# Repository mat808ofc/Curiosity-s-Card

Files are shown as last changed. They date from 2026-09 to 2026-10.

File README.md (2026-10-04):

# Curiosity's Card

### About
This is a custom business card with a nfc chip "NT3H2111W0FHKH", antenna "NXP's official Class 4 antenna" and a low-current 0603 package red LED, Vishay's "TLMS1000-GS15", which at 2mA (it's tested current for usage) only needs 1.75V (according to the Vf vs. If graphic in the datasheet). This is because the LED will work with the chip's energy harvesting feature, which will "harvest" energy from the nfc device (like a phone). The total voltage the chip can usually output with this technique is 2V, so the LED is inside the budget. I used the Ohm's Law to find the resistor value for the LED. 

R = (V_supply - V_LED) / I_desired

Vf - The forward voltage is the voltage it needs for a given current.
If - The forward current is the current actually flowing through the LED. Controls brightness. This is the value you target. Everything else in the calculation exists to make sure this number ends up where you want it.
They are related to each other. When more current flows through, Vf goes up as well.
V_supply: the total voltage available from the source (VOUT, ~2V in this case)
V_LED (Vf): the voltage the LED itself consumes at THE CHOSEN CURRENT!!

R = (2 − 1.75) / 0.002A = 125Ω, which is approx. 130Ω.

Aside from calculations, I also added personal branding, the Hack Club logo, some cool gradients, a qr code to my github repos and a section with most of the SMD package sizes (It's fun).

### INSPIRATION:
I haven't done projects for quite a long time because I was exhausted from it since the Flight controller (I was also working on my RC plane) so I decided to make a little weekend project, a custom business card, which is also I have honestly been wanting to make for quite a while now.

### CHALLENGES:
My biggest challenge was understanding the math and physics for the LED, it seemed super confusing at first but now I get it, and it makes a lot of sense. I also found it hard to understand the nfc chip and tag, but I ended up figuring it out.

### BOM:
| Part | MFR.Part # | Qty | Total Cost (USD) |  Link to part (lcsc) | Distributor |
|---|---|---|---|---|---|
| C1 (200nf 0603 capacitor) |  0603B204K160CT |  20 | $0.9140 | https://www.lcsc.com/pt/product-detail/C3833176.html?s_z=n_q_0603B204K160CT | JLCPCB |
| D1 (TLMS1000 0603 LED) |  TLMS1000-GS15 |  5 | $0.8605 | https://www.lcsc.com/pt/product-detail/C23070302.html?s_z=n_q_TLMS1000-GS15 | JLCPCB |
| R1 (130Ω 0402 resistor) |  RC0402FR-07130RL |  20 | $0.0800 | https://www.lcsc.com/pt/product-detail/C477610.html?s_z=n_q_RC0402FR-07130RL | JLCPCB |
| U1 (NXP NT3H2111W0FHKH) |  NT3H2111W0FHKH |  2 | $1.2324 | https://www.lcsc.com/pt/product-detail/C710403.html?s_z=n_q_NT3H2111W0FHKH | JLCPCB |
| Total: $3,0869 |

JLCPCB quote for assembly of 2 boards + shipping (Global Standard Direct Line: $8.48) + components with -$10 coupon: $26.76
{DEB36AE8-D00F-4259-A287-6ED29371B2AF}

(You can find the excel full BOM file in the project files)

# Grand Total: $26.76

### Extras:

This project does not need a case or anything 3D printed or designed, it is just a business card.
If you have any questions, DM me on slack: Mateus (mateus.flecha808)

## Schematic
{6E333D57-6D36-4BEA-881A-1B5B8A142C3A}

## PCB
{DF59C323-F329-4ACC-A75C-B1E4562BDE57}

## Render
{6B454F27-4811-417E-BAE5-E6EDF0D340DB}
The resistors on the SMD package sizing sections WILL NOT be assembled on the pcb! It will just be the footprints to display the different sizes.

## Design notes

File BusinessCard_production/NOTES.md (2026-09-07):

Coil to LA/LB, GND to ground, FD left open or wired to an MCU/LED if the field-detect feature is wanted, and EP (exposed pad) left open/floating per the datasheet.

No pours, no wires, no NOTHING near the coil and chip.

The chip can be near the coil.

LA/LB can be wired freely to the chip.

nfc is interesting

**The basic LED resistor formula:**

R = (V\_supply - V\_LED) / I\_desired

Vf - The forward voltage is the voltage it needs for a given current.

If - The forward current is the current actually flowing through the LED. Controls brightness. This is the value you target. Everything else in the calculation exists to make sure this number ends up where you want it.

They are related to each other. When more current flows through, Vf goes up as well.

The current is the same in every part of the circuit.

The total available voltage HAS to be spent between the resistor and the LED.

Formula: R = (V\_supply − V\_LED) / I\_desired

V\_supply: the total voltage available from the source (VOUT, \~2V in this case)

V\_LED (Vf): the voltage the LED itself consumes at YOUR CHOSEN CURRENT!!

(V\_supply − V\_LED): whatever voltage is "left over" after the LED takes its share, **this is the voltage the resistor needs to drop**

I\_desired (If): the current you want flowing through the LED (and therefore through the resistor too, since they're in series)

R: the resistance needed so that this leftover voltage, divided by this resistance, produces exactly the target current, this comes directly from **Ohm's Law (V = I × R, rearranged to R = V / I)**

**Finished Formula: R = (2 − 1.7) / 0.002A = 150 ------> R = 150 Ohms**

"mA" MUST BE CONVERTED TO "A"

If Vf (toll) was 1.65: (LED needs 1.65V at 2mA)

**R = 175 Ohms**

If Vf was 1.75: (LED needs 1.75V at 2mA)

**R = 125 Ohms**

If Vf was 1.8: (LED needs 1.8V at 2mA)

**R = 100 Ohms**

If the LED consumes more voltage, the resistor needs a smaller value, and if the LED consumes less voltage, the resistor needs a higher value

PART THAT WILL BE USED::

TLMS1000

COLOR: RED

LOW CURRENT

Vf for 2mA = approx. 1.75, so **R = 125 Ohms**

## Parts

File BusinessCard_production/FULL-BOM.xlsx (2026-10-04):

Components BOM
Part | MFR.Part # | Qty | Unit Cost (USD) | Total Cost (USD) | Link to part (LCSC) | Distributor
C1 (200nF 0603 capacitor) | 0603B204K160CT | 20 | $0.0457 | $0.9140 | https://www.lcsc.com/pt/product-detail/C3833176.html?s_z=n_q_0603B204K160CT | JLCPCB
D1 (TLMS1000 0603 LED) | TLMS1000-GS15 | 5 | $0.1721 | $0.8605 | https://www.lcsc.com/pt/product-detail/C23070302.html?s_z=n_q_TLMS1000-GS15 | JLCPCB
R1 (130Ω 0402 resistor) | RC0402FR-07130RL | 20 | $0.0040 | $0.0800 | https://www.lcsc.com/pt/product-detail/C477610.html?s_z=n_q_RC0402FR-07130RL | JLCPCB
U1 (NXP NT3H2111W0FHKH) | NT3H2111W0FHKH | 2 | $0.6162 | $1.2324 | https://www.lcsc.com/pt/product-detail/C710403.html?s_z=n_q_NT3H2111W0FHKH | JLCPCB
 |  |  | Components Total: | $3.0869
Note: Part qty is the minimum order qty from lcsc
JLCPCB Fabrication & Assembly Quote
Item | Details | Qty | Build Time | Price (USD)
PCB Prototype (business_card_Y10) | Y10-11917019A, Black, 1.2mm Thickness, HASL (with lead) — Special offer price (orig. $4.00) | 5 | 24 hours | $2.00
PCBA — Economic Assembly (top side) | SMT026100460931-11..., business_card_Y10 | 2 | 1-2 days | $26.28
 |  |  | Merchandise Total: | $28.28
 |  |  | Shipping Estimated (Global Standard Direct Line): | $8.48
 |  |  | Coupon: | -$10.00
 |  |  | Subtotal (Order Total): | $26.76
Grand Total (JLCPCB Order)
 |  |  | JLCPCB Order Subtotal: | $26.76
 |  |  | GRAND TOTAL: | $26.76

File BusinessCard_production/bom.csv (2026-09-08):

Designator | Footprint | Quantity (FOR 1 BOARD) | Value | LCSC Part #
C1 | 0805 | 1 | 200nF
D1 | 0603 | 1 | TLMS1000
E$1 | L_PICC_CLASS4_50PF_01 | 1 | ANTENNA COIL
R1 | 0402 | 1 | 130Ω
R2 | 0201 | 0 | R
R3 | 0402 | 0 | R
R4 | 0603 | 0 | R
R5 | 0805 | 0 | R
R6 | 1206 | 0 | R
R7 | 1210 | 0 | R
R8 | 2512 | 0 | R
U1 | XQFN-8_L1.6-W1.6-P0.50-BL_NT3H2111W0FHKH | 1 | NT3H2111W0FHKH | C710403

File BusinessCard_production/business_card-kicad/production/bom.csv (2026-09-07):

Designator | Footprint | Quantity | Value | LCSC Part #
C1 | 0805 | 1 | 200nF
D1 | 0603 | 1 | TLMS1000
E$1 | L_PICC_CLASS4_50PF_01 | 1
R1 | 0402 | 1 | 130
R2 | 0201 | 1 | R
R3 | 0402 | 1 | R
R4 | 0603 | 1 | R
R5 | 0805 | 1 | R
R6 | 1206 | 1 | R
R7 | 1210 | 1 | R
R8 | 2512 | 1 | R
U1 | XQFN-8_L1.6-W1.6-P0.50-BL_NT3H2111W0FHKH | 1 | NT3H2111W0FHKH | C710403

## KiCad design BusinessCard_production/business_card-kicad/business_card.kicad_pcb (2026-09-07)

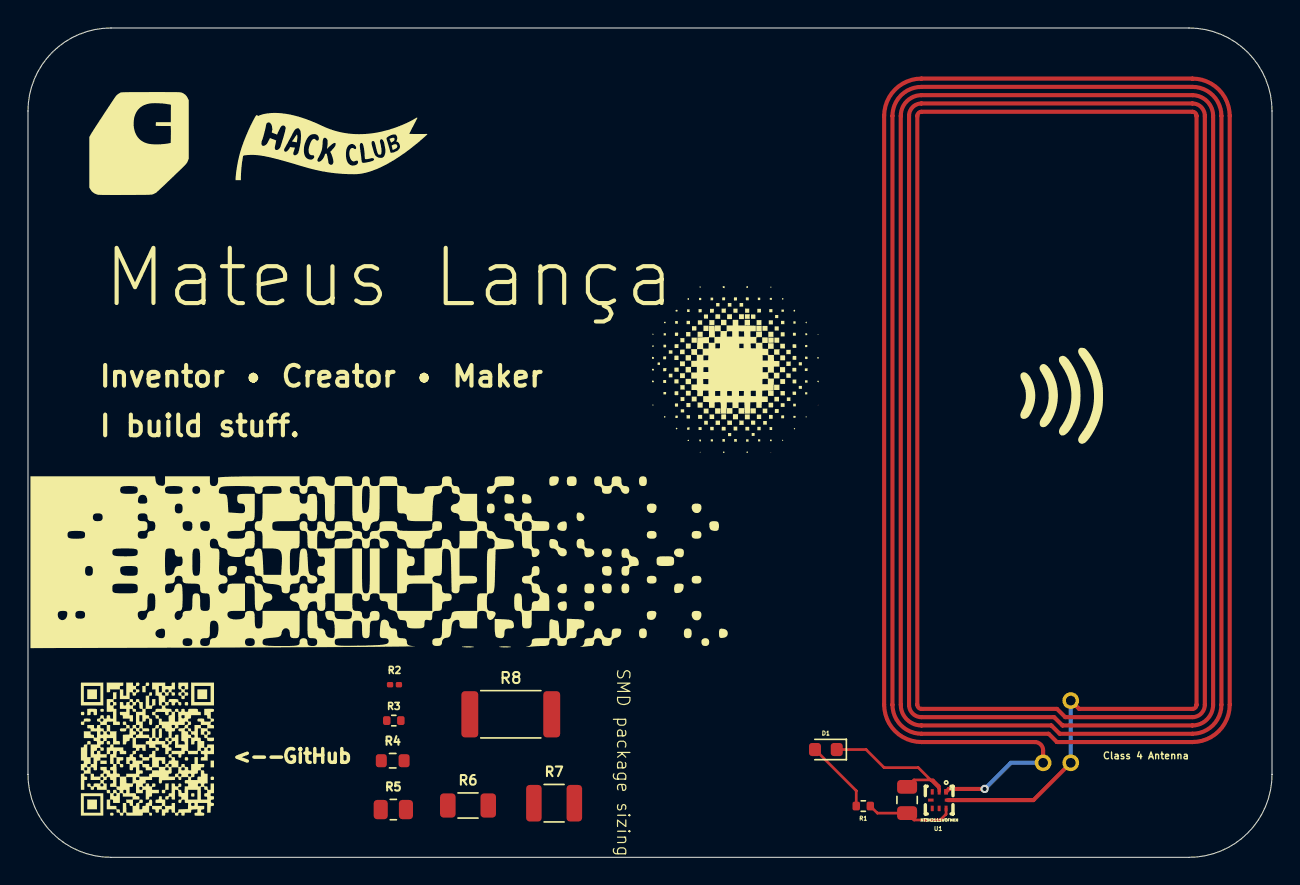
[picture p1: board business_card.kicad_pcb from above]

Board: 2 copper layers, 90.0 x 60.0 mm, 12 parts (0 on the bottom side), 4 nets.

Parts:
C1: 200nF; C_0805_2012Metric
D1: TLMS1000; LED_0603_1608Metric
E$1: L_PICC_CLASS4_50PF_01
R1: 130; R_0402_1005Metric
R2: R; R_0201_0603Metric
R3: R; R_0402_1005Metric
R4: R; R_0603_1608Metric
R5: R; R_0805_2012Metric
R6: R; R_1206_3216Metric
R7: R; R_1210_3225Metric
R8: R; R_2512_6332Metric
U1: NT3H2111W0FHKH; XQFN-8_L1.6-W1.6-P0.50-BL_NT3H2111W0FHKH

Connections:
/ANTENNA_LB: E$1.P$1, U1.8 (LB)
unnamed: D1.2 (A), R1.1
unnamed: C1.1, D1.1 (K), U1.2 (VSS)
unnamed: C1.2, R1.2, U1.7 (VOUT)

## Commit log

2026-09-07 Update README with project information and details
    Expanded project details including specifications, challenges, and BOM.
2026-10-04 Revise BOM with detailed parts and total costs
    Updated BOM section with detailed parts and costs, and revised total costs.
2026-10-04 Update README with JLCPCB quote and BOM info
    Added details about JLCPCB quote and BOM file location.
2026-10-22 Update README with image and product details
    Added an image to the README and provided details about the business card's NFC chip and LED specifications.
